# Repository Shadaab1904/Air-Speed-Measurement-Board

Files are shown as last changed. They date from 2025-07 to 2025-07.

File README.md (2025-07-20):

# Air-Speed-Measurement-Board
This project is a custom-designed PCB that integrates a **Sensirion SDP810 differential pressure sensor** with an **STM32F030F4Px microcontroller**. The board is designed for use in airspeed measurement applications, such as on drones and UAVs. It measures differential pressure via I²C, applies onboard filtering, converts it into airspeed (in m/s), and provides the result via an SPI interface to a master controller. An **interrupt pin** signals the availability of new data.

## 📦 Overview

- **Sensor**: Sensirion SDP810-500PA (differential pressure sensor)
- **Microcontroller**: STM32F030F4Px (ARM Cortex-M0)
- **Power**: 5V input with onboard 3.3V regulation
- **Interfaces**:
  - I²C (sensor side)
  - SPI (to master controller)
  - Read Interrupt Pin (signals new data ready)
  - SWD (for programming/debugging)
 
 ## 🎯 Purpose

This board acts as an **airspeed signal processing unit**. It reads differential pressure caused by the difference between total and static air pressure (using a pitot tube setup), computes the **dynamic pressure**, and derives the **airspeed** using Bernoulli’s principle.

## 🧠 Functional Description

### 1. **Sensor Interface (I²C)**
- The STM32 communicates with the SDP810 sensor using I²C.
- The sensor provides differential pressure readings in Pascal (Pa).

### 2. **Signal Processing**
- Raw pressure readings are digitally filtered.
- The airspeed \( v \) is calculated using:

v = sqrt 2. Delta P / rho
where:
- Delta P = differential pressure in Pa
- rhO = air density (typically 1.225 kg/m³ at sea level)

### 3. **Data Output (SPI + Interrupt)**
- Filtered airspeed data is provided to an SPI master.
- An interrupt output toggles to notify the master of new data availability.

## 🔧 Key Components
- STM32F030F4Px: ARM Cortex-M0 MCU
- SDP810-500PA: Differential pressure sensor with I²C output
- HT75xx-1 (SOT89): Low dropout 3.3V voltage regulator
- B5819W: Reverse polarity protection diode
- TVS Diode: ESD protection on power lines
- Crystal. External clock source for STM32
- Conn_01x10_Pin: Main interface header
- Capacitors, Resistors: Decoupling, pull-ups, filtering
- Status Indicator: Optional debug/status indicator
- Ferrite Bead: Noise suppression on power line

## 📐 Pin Interface 

- VCC (5V): Input power (to LDO regulator)
- GND: Ground
- SWDIO: SWD programming interface
- SWCLK: SWD clock
- SPI_MISO: SPI Slave Output (to master)
- SPI_MOSI: SPI Slave Input (from master)
- SPI_SCK: SPI clock
- SPI_CS: Chip Select
- INT_OUT: Interrupt pin (new data ready)
- GND: Ground

## ⚡ Power and Programming
### 🔋 Power Supply

- Supply 5V through pin 1.
- The HT75xx LDO steps it down to 3.3V for STM32 and sensor.

### 🧠 Programming (SWD)

- Use **ST-Link V2** or equivalent SWD debugger:
-  STM32 Pin | ST-Link Pin
-  SWDIO     | SWDIO
-  SWCLK     | SWCLK
-  GND       | GND
-  NRST      | NRST
- 3.3V (ref) | Vcc

## 📈 Applications

- Fixed-wing drone airspeed measurement
- Feedback loop for fan/blower control
- Wind tunnel experiments
- HVAC airflow monitoring

## 📂 Project structure
- `Pressure sensor.kicad_sch` – Schematic file
- `Pressure sensor_pcb` – PCB layout file
- `Pressure sensor_pro` – KiCad project file
- `STEP/` - Sensor 3D model
- `gerber/` – Gerber and drill files for fabrication
- `bom.csv` – Bill of Materials

- ## ⚙️ Tools
- Designed with [KiCad](https://kicad.org/)

- ## 📦 Fabrication
Use the files in the `gerber/` directory to order PCBs from manufacturers (e.g., JLCPCB etc.).

- ## 📄 License
MIT License – feel free to modify and use.

## 🙌 Contributions
Pull requests welcome! If you spot issues or have improvements, please open an issue or PR.

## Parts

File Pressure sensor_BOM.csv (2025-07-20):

Reference | Qty | Value | DNP | Exclude from BOM | Exclude from Board | Footprint | Datasheet
C1,C2,C9,C10 | 4 | 10u |  |  |  | Capacitor_SMD:C_0805_2012Metric | ~
C3,C4,C5,C8 | 4 | 100n |  |  |  | Capacitor_SMD:C_0402_1005Metric | ~
C6,C7 | 2 | 10p |  |  |  | Capacitor_SMD:C_0402_1005Metric | ~
D1 | 1 | B5819W |  |  |  | B5819W:SOD123FL
D2 | 1 | GREEN |  |  |  | LED_SMD:LED_0603_1608Metric | ~
D3 | 1 | BLUE |  |  |  | LED_SMD:LED_0603_1608Metric | ~
D4,D5,D6,D7,D8,D9,D10 | 7 | PESD5V0L1BA,115 |  |  |  | Diode_SMD:D_SOD-323 | ~
FB1,FB2 | 2 | 120R |  |  |  | Inductor_SMD:L_0603_1608Metric | ~
H1,H2,H3,H4 | 4 | MountingHole |  |  |  | MountingHole:MountingHole_2.2mm_M2 | ~
J1 | 1 | Conn_01x10_Pin |  |  |  | Connector_Molex:Molex_PicoBlade_53048-1010_1x10_P1.25mm_Horizontal | ~
J2 | 1 | TC2030-IDC-NL |  |  |  | TC2030-IDC-NL:TAG_TC2030-IDC-NL
R1,R2 | 2 | 510R |  |  |  | Resistor_SMD:R_0402_1005Metric | ~
R3,R6,R7,R8,R9,R10 | 6 | 22R |  |  |  | Resistor_SMD:R_0402_1005Metric | ~
R4,R5 | 2 | 2k2 |  |  |  | Resistor_SMD:R_0402_1005Metric | ~
U1 | 1 | HT75xx-1-SOT89 |  |  |  | Package_TO_SOT_SMD:SOT-89-3 | https://www.holtek.com/documents/10179/116711/HT75xx-1v250.pdf
U2 | 1 | STM32F030F4Px |  |  |  | Package_SO:TSSOP-20_4.4x6.5mm_P0.65mm | https://www.st.com/resource/en/datasheet/stm32f030f4.pdf
U3 | 1 | SDP810-500PA |  |  |  | CustomFootprints:SDP81x_SEN | SDP810-500PA
Y1 | 1 | 16MHz |  |  |  | Crystal:Crystal_SMD_3225-4Pin_3.2x2.5mm | ~

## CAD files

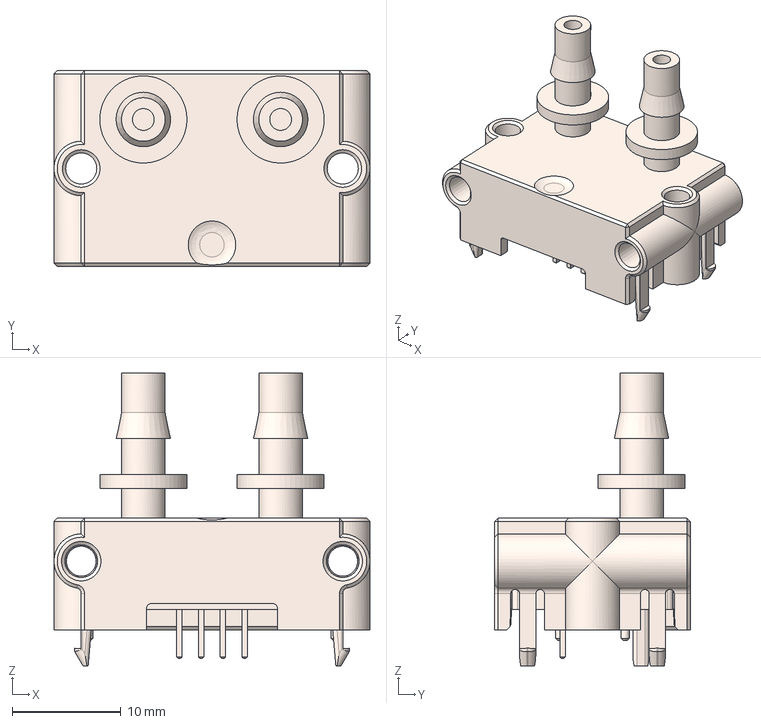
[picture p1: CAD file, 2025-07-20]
SDP810-500Pa.stp
29.0 x 18.0 x 26.8 mm

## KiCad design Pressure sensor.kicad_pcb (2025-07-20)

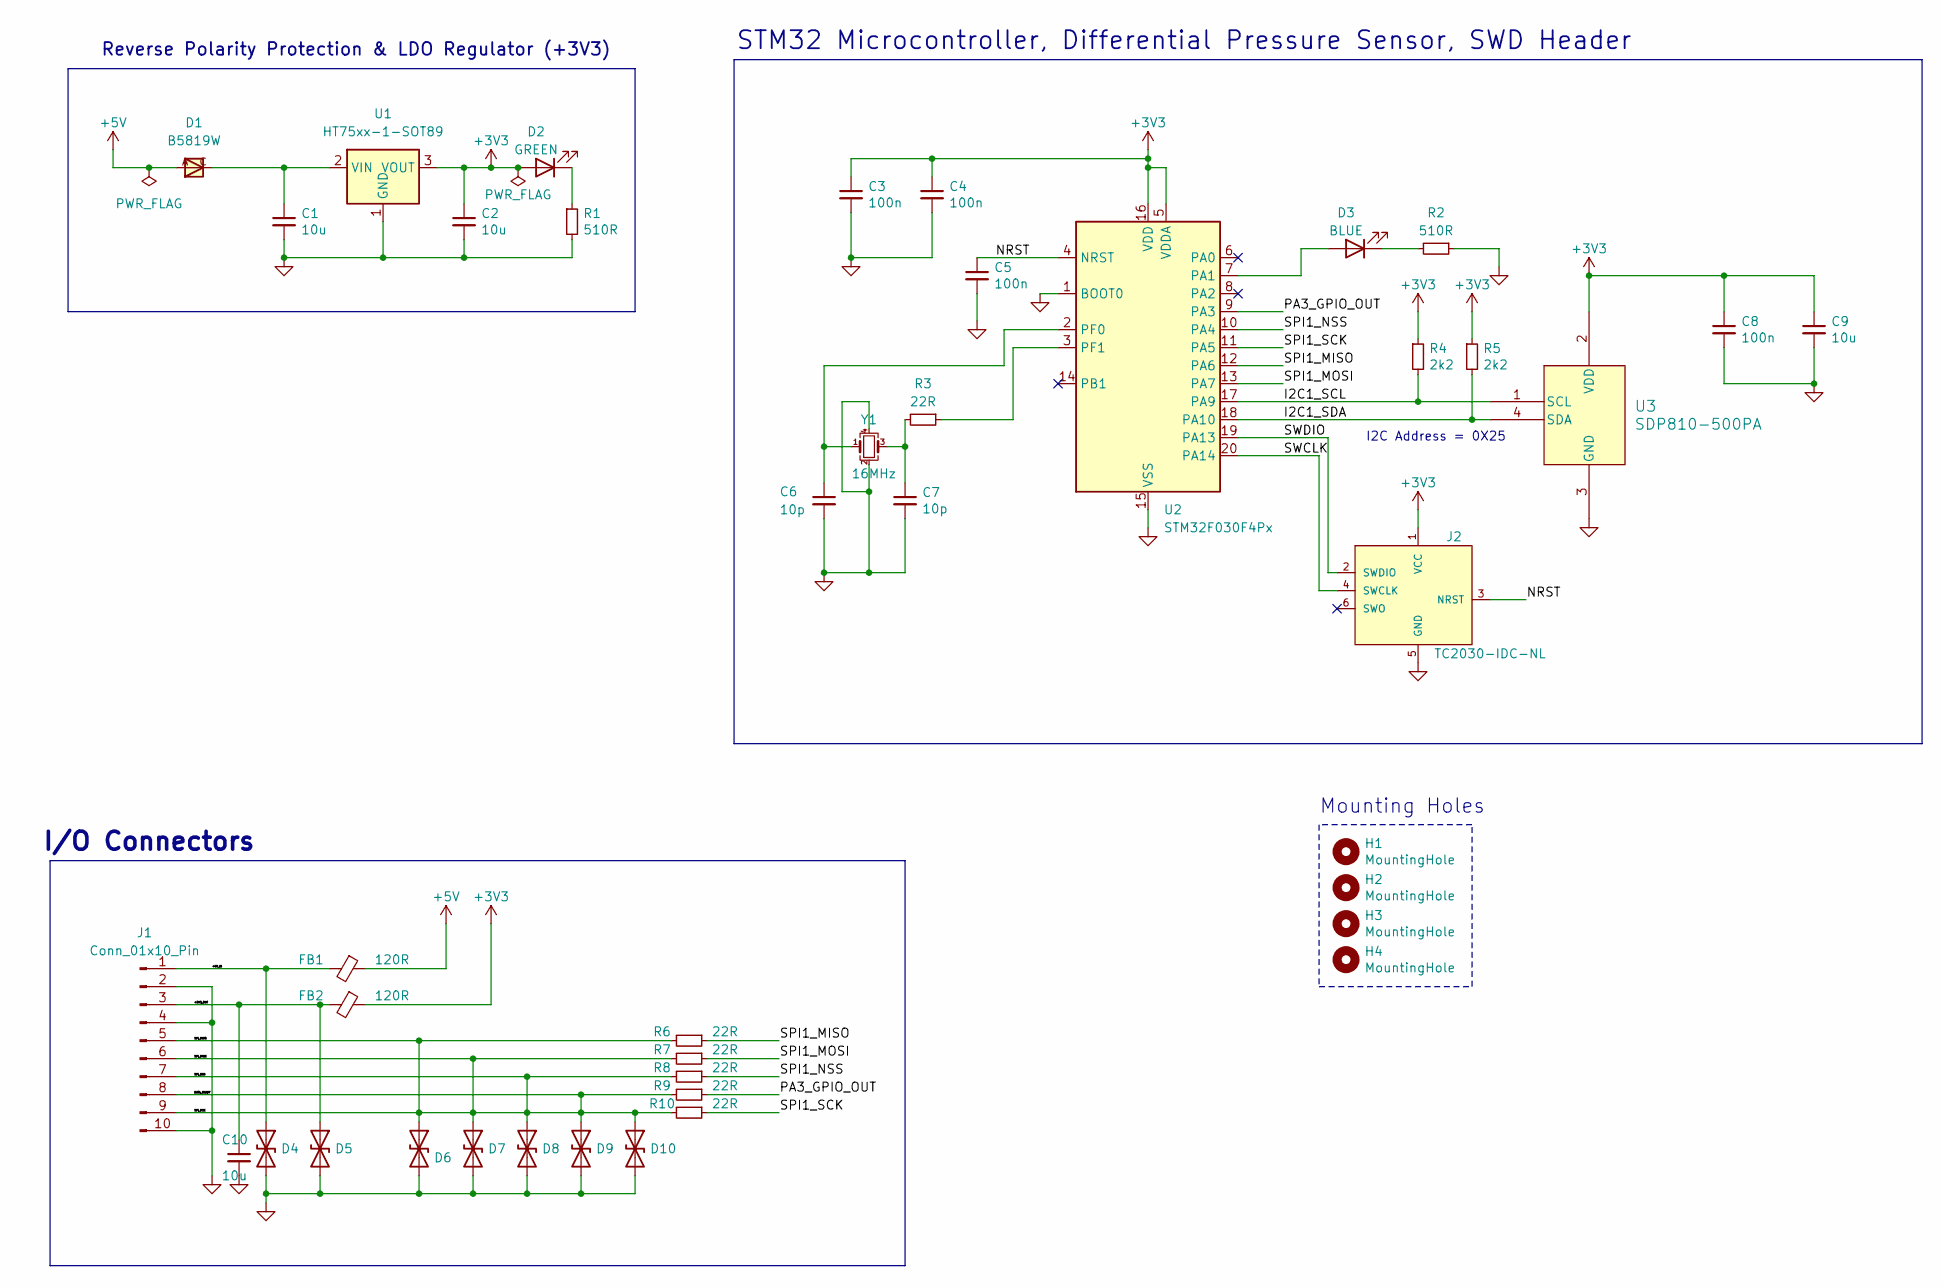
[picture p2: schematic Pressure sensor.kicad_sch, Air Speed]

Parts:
C1, C2, C9, C10: 10u; C_0805_2012Metric; LCSC Part # C15850
C3, C4, C5, C8: 100n; C_0402_1005Metric; LCSC Part # C1525
C6, C7: 10p; C_0402_1005Metric; LCSC Part # C32949
D1: B5819W; SOD123FL
D2: GREEN; LED_0603_1608Metric
D3: BLUE; LED_0603_1608Metric
D4, D5, D6, D7, D8, D9, D10: PESD5V0L1BA,115; D_SOD-323; LCSC Part # C85380
FB1, FB2: 120R; L_0603_1608Metric; LCSC Part # C85831
H1, H2, H3, H4: MountingHole; MountingHole_2.2mm_M2
J1: Conn_01x10_Pin; Molex_PicoBlade_53048-1010_1x10_P1.25mm_Horizontal
J2: TC2030-IDC-NL; TAG_TC2030-IDC-NL; PARTREV MS
R1, R2: 510R; R_0402_1005Metric; LCSC Part # C25123
R3, R6, R7, R8, R9, R10: 22R; R_0402_1005Metric; LCSC Part # C25092
R4, R5: 2k2; R_0402_1005Metric; LCSC Part # C25879
U1: HT75xx-1-SOT89; SOT-89-3
U2: STM32F030F4Px; TSSOP-20_4.4x6.5mm_P0.65mm
U3: SDP810-500PA; SDP81x_SEN
Y1: 16MHz; Crystal_SMD_3225-4Pin_3.2x2.5mm; LCSC Part # C13738

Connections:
+3V3: C2.1, C3.1, C4.1, C8.1, C9.1, D2.2 (A), FB2.1, J2.1 (VCC), R4.1, R5.1, U1.3 (VOUT), U2.5 (VDDA), U2.16 (VDD), U3.2 (VDD)
+5V: D1.A, FB1.1
/+3V3_OUT: C10.1, D5.1 (A1), FB2.2, J1.3
/+5V_IN: D4.1 (A1), FB1.2, J1.1
/DATA_READY: D6.1 (A1), D7.1 (A1), D8.1 (A1), D9.1 (A1), D10.1 (A1), J1.5, J1.6, J1.7, J1.8, J1.9, R6.2, R7.2, R8.2, R9.2, R10.2
/I2C1_SCL: R4.2, U2.17 (PA9), U3.1 (SCL)
/I2C1_SDA: R5.2, U2.18 (PA10), U3.4 (SDA)
/NRST: C5.1, J2.3 (NRST), U2.4 (NRST)
/PA3_GPIO_OUT: R9.1, U2.9 (PA3)
/SPI1_MISO: R6.1, U2.12 (PA6)
/SPI1_MOSI: R7.1, U2.13 (PA7)
/SPI1_NSS: R8.1, U2.10 (PA4)
/SPI1_SCK: R10.1, U2.11 (PA5)
/SWCLK: J2.4 (SWCLK), U2.20 (PA14)
/SWDIO: J2.2 (SWDIO), U2.19 (PA13)
GND: C1.2, C2.2, C3.2, C4.2, C5.2, C6.2, C7.2, C8.2, C9.2, C10.2, D4.2 (A2), D5.2 (A2), D6.2 (A2), D7.2 (A2), D8.2 (A2), D9.2 (A2), D10.2 (A2), J1.2, J1.4, J1.10, J2.5 (GND), R1.2, R2.1, U1.1 (GND), U2.1 (BOOT0), U2.15 (VSS), U3.3 (GND), Y1.2, Y1.4
unnamed: C7.1, R3.2, Y1.3
unnamed: D2.1 (K), R1.1
unnamed: D3.2 (A), U2.7 (PA1)
unnamed: D3.1 (K), R2.2
unnamed: C1.1, D1.C, U1.2 (VIN)
unnamed: C6.1, U2.2 (PF0), Y1.1
unnamed: R3.1, U2.3 (PF1)

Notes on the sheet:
I2C Address = 0X25
Mounting Holes
I/O Connectors
Reverse Polarity Protection & LDO Regulator (+3V3)
STM32 Microcontroller, Differential Pressure Sensor, SWD Header

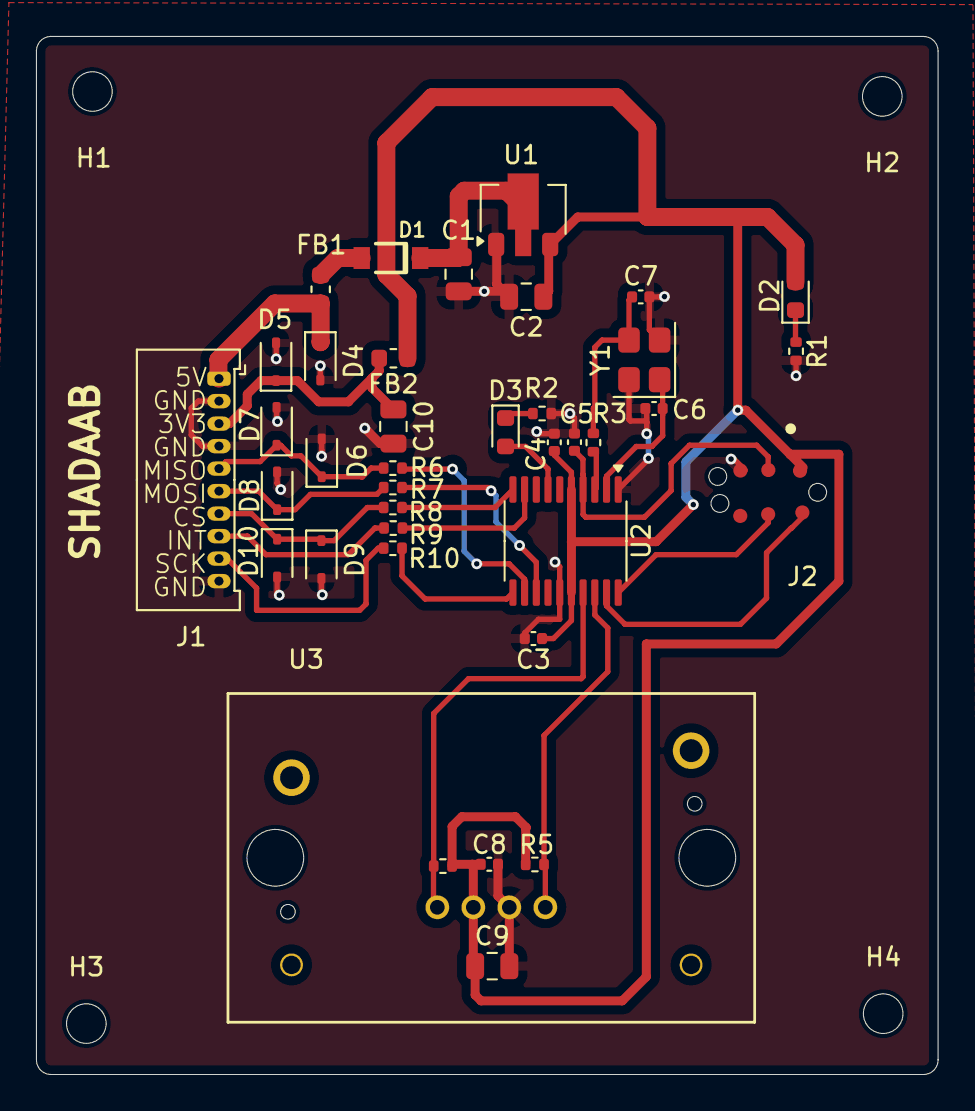
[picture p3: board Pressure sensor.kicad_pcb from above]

Board: 2 copper layers, 50.1 x 57.7 mm, 42 parts (0 on the bottom side), 23 nets.
